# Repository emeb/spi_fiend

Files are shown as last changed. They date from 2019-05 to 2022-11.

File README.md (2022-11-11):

# spi_fiend
STM32F042-based USB to SPI device for programming iCE40 FPGAs

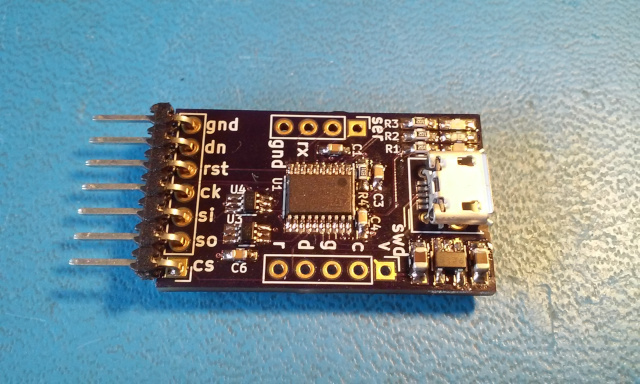
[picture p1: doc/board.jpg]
board


Most open-source projects that use Lattice iCE40 FPGAs rely on the FTDI
FT2232 High-speed UART/FIFO chip to provide a SPI interface for programming
the FPGA and SPI Flash chip which contains the bitstream for self-configuration
at power-up. I've got nothing against FTDI, but the chips are big, require
a crystal and are fairly expensive in DIY quantities. On top of that I've been
using STM32 for years and have been looking for an excuse to dig into some
more USB applications so a USB to SPI bridge seemed like a good place to start.

This device uses the small and inexpensive STM32F042F6P6 in a 20-pin TSSOP
package. It supports crystal-less USB operation by syncing its internal RC
oscillator to the USB SOF signal and has enough SRAM and Flash to support a
moderately complex feature set:

* USB powered
* Crystal-less operation
* Presents an ordinary ACM / CDC class device that looks like a serial port.
* Supports direct loading into the iCE40 SRAM for quick development cycles.
* Supports read/write/erase of standard SPI Flash devices used for FPGA configuration.
* Includes automatic swapping of MOSI/MISO when switching between FPGA and SPI Flash.
* MCU Serial port is pinned out for debugging and future expansion.

## prerequisites
To build this you will need the following tools:

* Kicad - schematic & PCB editor.
* GCC ARM Embedded - cross-compiler for ARM Cortex M: https://developer.arm.com/tools-and-software/open-source-software/developer-tools/gnu-toolchain/gnu-rm
* dfu-util - USB DFU driver application available in most distributions.
* Basic Linux user C compiler (for host application)

## Building Hardware

The board design is available in the 'hardware' directory. The Kicad PCB can
be submitted directly to OSHpark.com, or traditional Gerbers can be exported
using the application. Part values and packages are noted in the schematic.

Note: in the Revision 1 PCB layout the USB connector doesn't overhang the PCB
edge and there is a slight interference with the lower lip. Filing a slight
chamfer on the PCB edge under the connector will allow it to sit flush to the
board.

## Building Firmware

The [Firmware README](firmware/README.md) has instructions on building the
preferred firmware for the SPI Fiend.

## Building Host Application

The host appliction runs on a Linux PC and communicates with the hardware
device via standard USB Serial protocols. Build the host application by changing
to the 'host' directory and executing 'make'. The built-in help should provide
a guide to available options, but here's a quick list of common actions:

* load a binary into the FPGA: ./cdc_prog BINARY_FILE
* load a binary into SPI Flash: ./cdc_prog -a ADDRESS -w BINARY_FILE
* read SPI flash contents to a file: ./cdc_prog -a ADDRESS -l LENGTH -r > OUTPUT_FILE
* erase SPI FLASH block: ./cdc_prog -a ADDRESS -e
* read SPI Flash ID: ./cdc_prog -i

In ordinary operation, the LED nearest the USB connector lights to indicate powerup,
the center LED lights when an error is detected during operation and the outer LED
lights when programming SPI flash.

## Status
### 2019-05-06
Initial commit with hardware, firmware and host application

### 2022-11-11
Updated with dual firmware that supports FPGA, flash and UART

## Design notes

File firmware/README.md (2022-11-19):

# spi_fiend
This is the embedded firmware for the SPI Fiend. There are two different builds
here:
* single - this is the original firmware based on the ST USB stack. It provides
one CDC device which is able to program FPGAs or SPI flash chips.
* dual - this is the preferred new firmware based on the TinyUSB stack. It
provides two CDC devices, one for programming FPGA and SOI Flash and a second one
for serial UART I/O.

## Prerequisites
The preferred dual firmware requires the TinyUSB repo. Please be sure to get
that by executing the command
```
git submodule update --init
```

## Building
Go into the desired directory `dual` or `single` and run `make` to build the
binary file.

## Installing
Connect the SPI Fiend hardware to your host USB and press both the `BOOT` and
`RST` buttons to put it into DFU bootloader mode. Then run
```
make dfu
```
to load the new firmware binary into the hardware.

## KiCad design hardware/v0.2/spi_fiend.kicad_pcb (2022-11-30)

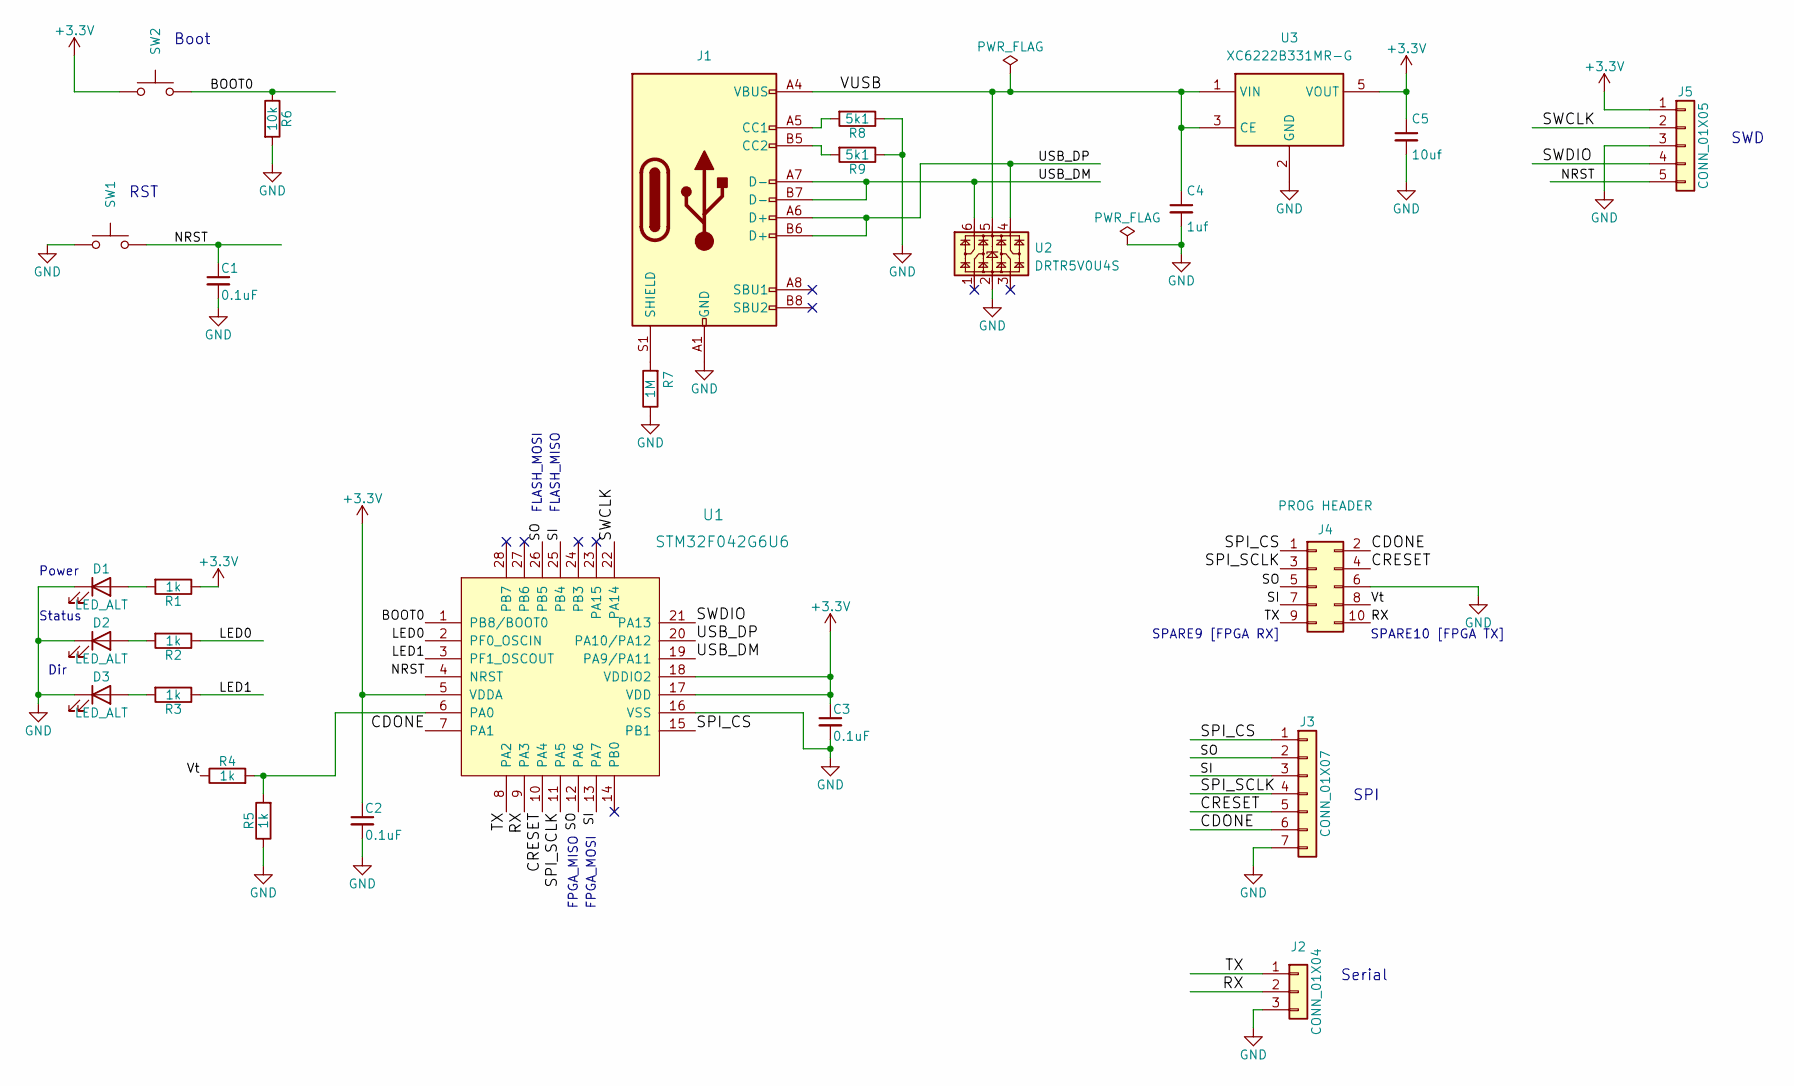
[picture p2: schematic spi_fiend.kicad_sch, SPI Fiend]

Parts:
C1, C2, C3: 0.1uF; C_0402_1005Metric
C4: 1uf; C_0402_1005Metric
C5: 10uf; C_0805_2012Metric
D1, D2, D3: LED_ALT; LED_0603_1608Metric
J1: USB_C_Receptacle_USB2.0; USB_C_Receptacle_HRO_TYPE-C-31-M-12
J2: CONN_01X04; PinHeader_1x03_P2.54mm_Vertical
J3: CONN_01X07; PinHeader_1x07_P2.54mm_Vertical
J4: PROG HEADER; PinHeader_2x05_P1.27mm_Vertical_SMD
J5: CONN_01X05; PinHeader_1x05_P2.54mm_Vertical
R1, R2, R3, R4, R5: 1k; R_0402_1005Metric
R6: 10k; R_0402_1005Metric
R7: 1M; R_0402_1005Metric
R8, R9: 5k1; R_0402_1005Metric
SW1, SW2: SW_Push; SW_SPST_PTS815
U1: STM32F042G6U6; IC_STM32F042G6U6
U2: DRTR5V0U4S; SOT-363_SC-70-6
U3: XC6222B331MR-G; SOT-23-5

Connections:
+3.3V: C2.1, C3.1, C5.1, J5.1, R1.1, SW2.1, U1.5 (VDDA), U1.17 (VDD), U1.18 (VDDIO2), U3.5 (VOUT)
/BOOT0: R6.1, SW2.2, U1.1 (PB8/BOOT0)
/CDONE: J3.6, J4.2, U1.7 (PA1)
/CRESET: J3.5, J4.4, U1.10 (PA4)
/LED0: R2.1, U1.2 (PF0_OSCIN)
/LED1: R3.1, U1.3 (PF1_OSCOUT)
/NRST: C1.1, J5.5, SW1.2, U1.4 (NRST)
/RX: J2.2, J4.10, U1.9 (PA3)
/SI: J3.3, J4.7, U1.13 (PA7), U1.25 (PB4)
/SO: J3.2, J4.5, U1.12 (PA6), U1.26 (PB5)
/SPI_CS: J3.1, J4.1, U1.15 (PB1)
/SPI_SCLK: J3.4, J4.3, U1.11 (PA5)
/SWCLK: J5.2, U1.22 (PA14)
/SWDIO: J5.4, U1.21 (PA13)
/TX: J2.1, J4.9, U1.8 (PA2)
/USB_DM: J1.A7 (D-), J1.B7 (D-), U1.19 (PA9/PA11), U2.6
/USB_DP: J1.A6 (D+), J1.B6 (D+), U1.20 (PA10/PA12), U2.4
/VUSB: C4.1, J1.A4 (VBUS), J1.A9 (VBUS), J1.B4 (VBUS), J1.B9 (VBUS), U2.5, U3.1 (VIN), U3.3 (CE)
/Vt: J4.8, R4.1
GND: C1.2, C2.2, C3.2, C4.2, C5.2, D1.1 (K), D2.1 (K), D3.1 (K), J1.A1 (GND), J1.A12 (GND), J1.B1 (GND), J1.B12 (GND), J2.3, J3.7, J4.6, J5.3, R5.1, R6.2, R7.1, R8.1, R9.1, SW1.1, U1.16 (VSS), U2.2, U3.2 (GND)
unnamed: D1.2 (A), R1.2
unnamed: D2.2 (A), R2.2
unnamed: D3.2 (A), R3.2
unnamed: J1.A5 (CC1), R8.2
unnamed: J1.B5 (CC2), R9.2
unnamed: J1.S1 (SHIELD), R7.2
unnamed: R4.2, R5.2, U1.6 (PA0)

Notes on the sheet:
FPGA_MISO
SWD
FPGA_MOSI
Serial
RST
Status
SPI
Power
Dir
FLASH_MOSI
Boot
SPARE9 [FPGA RX]
FLASH_MISO
SPARE10 [FPGA TX]

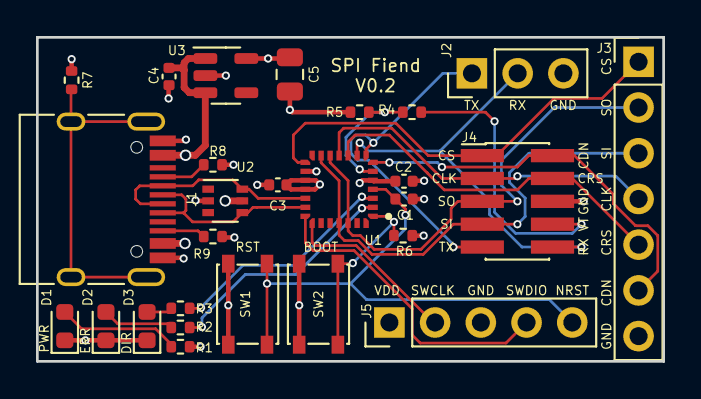
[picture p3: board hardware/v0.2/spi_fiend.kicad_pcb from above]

Board: 4 copper layers, 34.8 x 18.0 mm, 28 parts (1 on the bottom side), 27 nets.

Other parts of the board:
Ref**: Val**; avatar_small

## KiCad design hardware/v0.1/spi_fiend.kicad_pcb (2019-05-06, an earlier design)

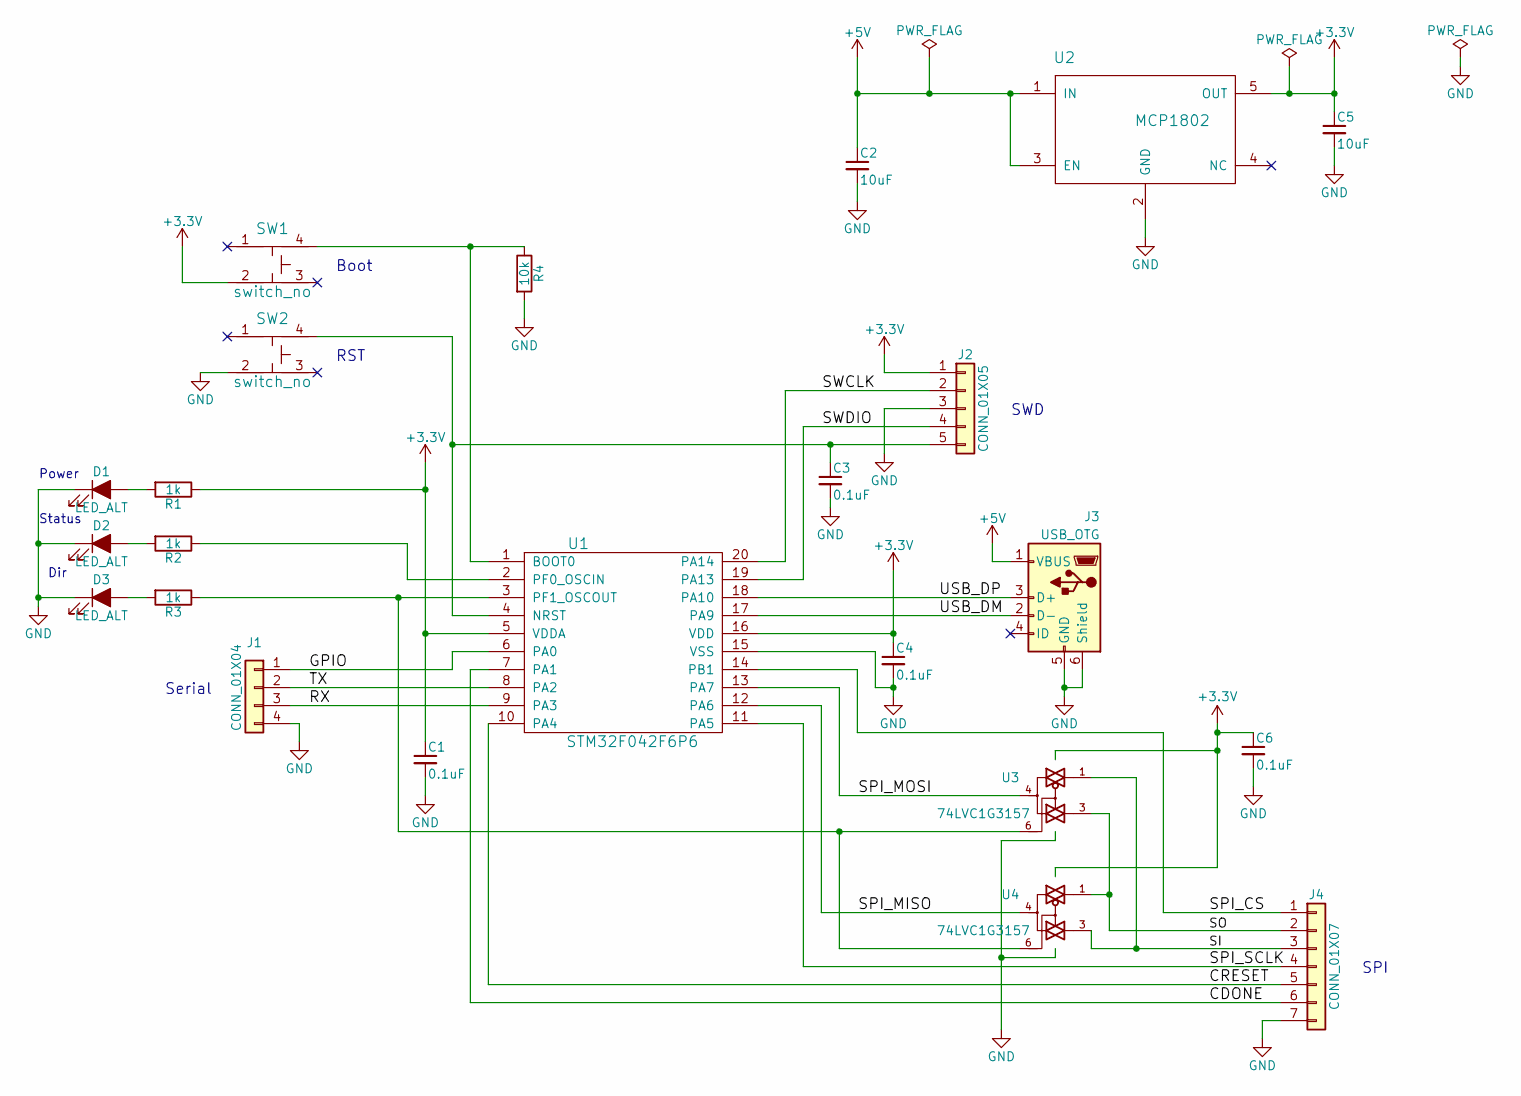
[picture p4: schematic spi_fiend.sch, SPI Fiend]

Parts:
C1, C3, C4, C6: 0.1uF; C_0603_HandSoldering
C2, C5: 10uF; C_0805_HandSoldering
D1, D2, D3: LED_ALT; LED_0603_HandSoldering
J1: CONN_01X04; Pin_Header_Straight_1x04_Pitch2.54mm
J2: CONN_01X05; Pin_Header_Straight_1x05_Pitch2.54mm
J3: USB_OTG; USB_Micro-B_10103594-0001LF_NoSlot
J4: CONN_01X07; Pin_Header_Straight_1x07_Pitch2.54mm
R1, R2, R3: 1k; R_0603_HandSoldering
R4: 10k; R_0603_HandSoldering
SW1, SW2: switch_no; PUSHBUTTON_SMD_KMR2
U1: STM32F042F6P6; TSSOP-20_4.4x6.5mm_Pitch0.65mm
U2: MCP1802; SOT-23-5_HandSoldering
U3, U4: 74LVC1G3157; SOT-363_SC-70-6_Handsoldering

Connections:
+3V3: C1.1, C4.1, C5.1, C6.1, J2.1, R1.1, SW1.2, U1.5 (VDDA), U1.16 (VDD), U2.5 (OUT), U3.5 (VCC), U4.5 (VCC)
+5V: C2.1, J3.1 (VBUS), U2.1 (IN), U2.3 (EN)
/CDONE: J4.6, U1.7 (PA1)
/CRESET: J4.5, U1.10 (PA4)
/GPIO: J1.1, U1.6 (PA0)
/RX: J1.3, U1.9 (PA3)
/SI: J4.3, U3.1, U4.3
/SO: J4.2, U3.3, U4.1
/SPI_CS: J4.1, U1.14 (PB1)
/SPI_MISO: U1.12 (PA6), U4.4
/SPI_MOSI: U1.13 (PA7), U3.4
/SPI_SCLK: J4.4, U1.11 (PA5)
/SWCLK: J2.2, U1.20 (PA14)
/SWDIO: J2.4, U1.19 (PA13)
/TX: J1.2, U1.8 (PA2)
/USB_DM: J3.2 (D-), U1.17 (PA9)
/USB_DP: J3.3 (D+), U1.18 (PA10)
GND: C1.2, C2.2, C3.2, C4.2, C5.2, C6.2, D1.1 (K), D2.1 (K), D3.1 (K), J1.4, J2.3, J3.5 (GND), J3.6 (Shield), J4.7, R4.2, SW2.2, U1.15 (VSS), U2.2 (GND), U3.2 (GND), U4.2 (GND)
unnamed: C3.1, J2.5, SW2.4, U1.4 (NRST)
unnamed: D1.2 (A), R1.2
unnamed: D2.2 (A), R2.2
unnamed: D3.2 (A), R3.2
unnamed: R2.1, U1.2 (PF0_OSCIN)
unnamed: R3.1, U1.3 (PF1_OSCOUT), U3.6, U4.6
unnamed: R4.1, SW1.4, U1.1 (BOOT0)

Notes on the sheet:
Boot
RST
Serial
SPI
SWD
Power
Status
Dir

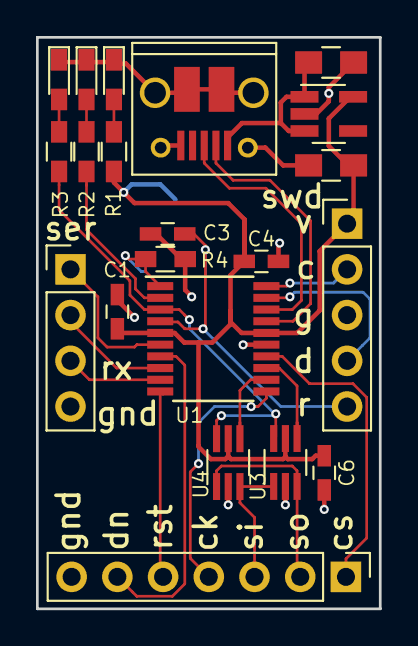
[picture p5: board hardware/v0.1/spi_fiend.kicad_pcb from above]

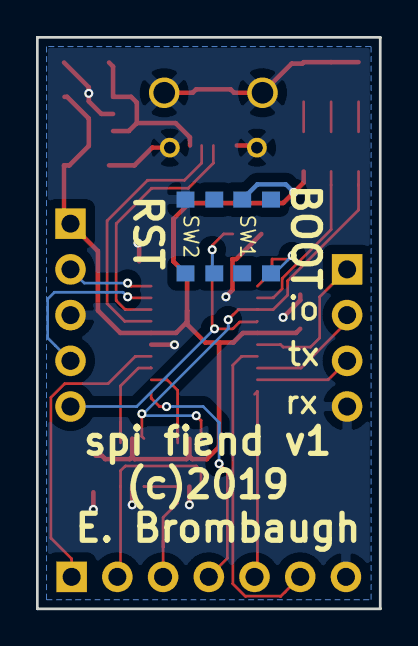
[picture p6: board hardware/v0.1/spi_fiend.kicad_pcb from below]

Board: 2 copper layers, 19.1 x 31.8 mm, 23 parts (2 on the bottom side), 25 nets.

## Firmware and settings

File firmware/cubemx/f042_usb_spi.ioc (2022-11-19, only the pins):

Mcu.UserName=STM32F042F6Px
PA0.GPIO_Label=GPIO0
PA0.Signal=GPIO_Output
PA1.GPIO_Label=CDONE
PA1.Signal=GPIO_Input
PA11.Signal=USB_DM
PA12.Signal=USB_DP
PA13.Signal=SYS_SWDIO
PA14.Signal=SYS_SWCLK
PA2.Signal=USART2_TX
PA3.Signal=USART2_RX
PA4.GPIO_Label=CRST
PA4.Signal=GPIO_Output
PA5.Signal=SPI1_SCK
PA6.Signal=SPI1_MISO
PA7.Signal=SPI1_MOSI
PB1.GPIO_Label=SPI_CS
PB1.Signal=GPIO_Output
PB8.GPIO_Label=BOOT
PB8.Signal=GPIO_Output
PF0-OSC_IN.GPIO_Label=Status
PF0-OSC_IN.Signal=GPIO_Output
PF1-OSC_OUT.GPIO_Label=DIR
PF1-OSC_OUT.Signal=GPIO_Output

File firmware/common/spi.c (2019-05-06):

/*
 * spi.h - spi driver for F042_usb_spi
 * 01-23-2019 E. Brombaugh
 */

#include "spi.h"
#include "tim.h"
#include "led.h"

/* macros to define pins */
#define SPI_CS_PIN                        GPIO_PIN_1
#define SPI_CS_GPIO_PORT                  GPIOB
#define SPI_RST_PIN                       GPIO_PIN_4
#define SPI_RST_GPIO_PORT                 GPIOA
#define SPI_DONE_PIN                      GPIO_PIN_1
#define SPI_DONE_GPIO_PORT                GPIOA

/* macros for GPIO setting */
#define SPI_CS_LOW()     HAL_GPIO_WritePin(SPI_CS_GPIO_PORT,SPI_CS_PIN,GPIO_PIN_RESET)
#define SPI_CS_HIGH()    HAL_GPIO_WritePin(SPI_CS_GPIO_PORT,SPI_CS_PIN,GPIO_PIN_SET)
#define SPI_RST_LOW()    HAL_GPIO_WritePin(SPI_RST_GPIO_PORT,SPI_RST_PIN,GPIO_PIN_RESET)
#define SPI_RST_HIGH()   HAL_GPIO_WritePin(SPI_RST_GPIO_PORT,SPI_RST_PIN,GPIO_PIN_SET)
#define SPI_DONE_GET()   HAL_GPIO_ReadPin(SPI_DONE_GPIO_PORT, SPI_DONE_PIN)
#define ICE5_SPI_DUMMY_BYTE   0xFF
#define SPI_SWAP_MOSI()  led_on(LED1)
#define SPI_NORM_MOSI()  led_off(LED1)


/* SPI port handle */
static SPI_HandleTypeDef SpiHandle;

/* flash write state */
uint32_t fpw_addr, fpw_len, fpw_ptr;
uint8_t fpw_buffer[256];

/*
 * get SPI signals on/off the bus
 */
void spi_oe(uint8_t state)
{
	GPIO_InitTypeDef GPIO_InitStructure;
	
	if(state)
	{
		/* Configure SPI1 CLK/MOSI/MISO as alternate function push-pull */
		GPIO_InitStructure.Pin = GPIO_PIN_7|GPIO_PIN_6|GPIO_PIN_5;
		GPIO_InitStructure.Mode = GPIO_MODE_AF_PP;
		GPIO_InitStructure.Speed = GPIO_SPEED_FREQ_HIGH;
		GPIO_InitStructure.Pull = GPIO_NOPULL;
		GPIO_InitStructure.Alternate = GPIO_AF0_SPI1;
		HAL_GPIO_Init(GPIOA, &GPIO_InitStructure);
	}
	else
	{
		/* Configure SPI1 CLK/MOSI/MISO as input /w pullup */
		GPIO_InitStructure.Pin = GPIO_PIN_7|GPIO_PIN_6|GPIO_PIN_5;
		GPIO_InitStructure.Mode = GPIO_MODE_INPUT;
		GPIO_InitStructure.Speed = GPIO_SPEED_FREQ_HIGH;
		GPIO_InitStructure.Pull = GPIO_PULLUP;
		GPIO_InitStructure.Alternate = GPIO_AF0_SPI1;
		HAL_GPIO_Init(GPIOA, &GPIO_InitStructure);
	}
}

/*
 * Initialize the spi port and associated controls
 */
void spi_init(void)
{
	GPIO_InitTypeDef GPIO_InitStructure;
	
	/* Enable GPIO clocks */
	__HAL_RCC_GPIOA_CLK_ENABLE();
	__HAL_RCC_GPIOB_CLK_ENABLE();

	/* Setup GPIO control bits */
	SPI_RST_HIGH();
	SPI_CS_HIGH();
	
	/* CS pin configuration - OD w/ PU to allow multi master */
	GPIO_InitStructure.Pin =  SPI_CS_PIN;
	GPIO_InitStructure.Mode = GPIO_MODE_OUTPUT_OD;
	GPIO_InitStructure.Speed = GPIO_SPEED_FREQ_HIGH;
	GPIO_InitStructure.Pull = GPIO_PULLUP;
	HAL_GPIO_Init(SPI_CS_GPIO_PORT, &GPIO_InitStructure);
    
	/* RST pin configuration */
	GPIO_InitStructure.Pin =  SPI_RST_PIN;
	GPIO_InitStructure.Mode = GPIO_MODE_OUTPUT_PP;
	GPIO_InitStructure.Speed = GPIO_SPEED_FREQ_HIGH;
	GPIO_InitStructure.Pull = GPIO_NOPULL;
	HAL_GPIO_Init(SPI_RST_GPIO_PORT, &GPIO_InitStructure);
    
	/* Disable SPI outputs */
	spi_oe(0);
	
	/* Enable the SPI peripheral */
    __HAL_RCC_SPI1_CLK_ENABLE();
    
	SpiHandle.Instance               = SPI1;
	SpiHandle.Init.BaudRatePrescaler = SPI_BAUDRATEPRESCALER_8;
	SpiHandle.Init.Direction         = SPI_DIRECTION_2LINES;
	SpiHandle.Init.CLKPhase          = SPI_PHASE_1EDGE;
	SpiHandle.Init.CLKPolarity       = SPI_POLARITY_LOW;
	SpiHandle.Init.DataSize          = SPI_DATASIZE_8BIT;
	SpiHandle.Init.FirstBit          = SPI_FIRSTBIT_MSB;
	SpiHandle.Init.TIMode            = SPI_TIMODE_DISABLE;
	SpiHandle.Init.CRCCalculation    = SPI_CRCCALCULATION_DISABLE;
	SpiHandle.Init.CRCPolynomial     = 7;
	SpiHandle.Init.NSS               = SPI_NSS_SOFT;
	SpiHandle.Init.Mode              = SPI_MODE_MASTER;
	HAL_SPI_Init(&SpiHandle);

	/* Enable the SPI peripheral */
    __HAL_SPI_ENABLE(&SpiHandle);
}

/*
 * send a byte and receive a byte via spi
 */
uint8_t spi_txrx(uint8_t data)
{
	/* Wait until the transmit buffer is empty */
	while(__HAL_SPI_GET_FLAG(&SpiHandle, SPI_FLAG_TXE) == RESET)
	{
	}

	/* Send the byte */
	*(__IO uint8_t *) ((uint32_t)SPI1+0x0C) = data;
	
	/* Wait to receive a byte*/
	while(__HAL_SPI_GET_FLAG(&SpiHandle, SPI_FLAG_RXNE) == RESET)
	{
	}

	/* get the byte read from the SPI bus */ 
	data = *(__IO uint8_t *) ((uint32_t)SPI1+0x0C);
	
	return data;
}

/*
 * Send a block of data bytes via SPI
 */
uint32_t spi_send_data(uint8_t *data, uint32_t sz)
{	
    /* send all bytes */
	while(sz--)
    {
        spi_txrx(*data++);
	}
    
    return 0;
}

/*
 * start the config process
 */
uint8_t spi_config_start(void)
{
    uint8_t retval = 0;
	uint32_t timeout;
	
	/* Enable SPI port onto bus */
	spi_oe(1);
	
	/* drop reset bit */
	SPI_RST_LOW();
	
	/* wait 1us */
	tim_usleep(1);
    
	/* drop CS bit to signal slave mode */
	SPI_CS_LOW();
	
	/* delay >200ns to allow FPGA to recognize reset */
	tim_usleep(200);
    
	/* Wait for done bit to go inactive */
	timeout = 1000;
	while(timeout && (SPI_DONE_GET()==GPIO_PIN_SET))
	{
		timeout--;
	}
	if(!timeout)
	{
		/* Done bit didn't respond to Reset */
		retval = 1;
	}
    
	/* raise reset w/ CS low for SPI SS mode */
	SPI_RST_HIGH();
	
	/* delay >300us to allow FPGA to clear */
	tim_usleep(2000);
    
    return retval;
}

/*
 * finish the config process
 */
uint8_t spi_config_finish(void)
{
    uint8_t retval = 0;
	uint32_t timeout;
	
    /* diagnostic - raise CS for final runout */
	//SPI_CS_HIGH();
    
    /* send clocks while waiting for DONE to assert */
	timeout = 1000;
	while(timeout && (SPI_DONE_GET()==GPIO_PIN_RESET))
	{
		spi_txrx(ICE5_SPI_DUMMY_BYTE);
		timeout--;
	}
	if(!timeout)
	{
		/* FPGA didn't configure correctly */
		retval = 1;
	}
	
	/* send at least 49 more clocks */
	spi_txrx(ICE5_SPI_DUMMY_BYTE);
	spi_txrx(ICE5_SPI_DUMMY_BYTE);
	spi_txrx(ICE5_SPI_DUMMY_BYTE);
	spi_txrx(ICE5_SPI_DUMMY_BYTE);
	spi_txrx(ICE5_SPI_DUMMY_BYTE);
	spi_txrx(ICE5_SPI_DUMMY_BYTE);
	spi_txrx(ICE5_SPI_DUMMY_BYTE);

	/* Raise CS bit for subsequent slave transactions */
	SPI_CS_HIGH();
	
	/* Remove SPI port from bus */
	spi_oe(0);
	
	/* no error handling for now */
	return retval;
}

/*
 * prep for flash access
 */
void spi_flash_access(uint8_t state)
{
	if(state)
	{
		/* set up */
		SPI_RST_LOW();		/* disable the FPGA to get the bus */
		SPI_SWAP_MOSI();	/* swap mosi/miso for flash access */
		spi_oe(1);			/* Enable SPI port onto bus */
	}
	else
	{
		/* teardown */
		spi_oe(0);			/* Remove SPI port from bus */
		SPI_NORM_MOSI();	/* restore mosi/miso order */
		SPI_RST_HIGH();		/* enable the FPGA */
	}
}

/*
 * powerup flash
 */
void spi_flash_powerup(void)
{
	SPI_CS_LOW();			/* drop CS bit to access the memory */
	
	/* power up command */
	spi_txrx(0xab);
	
	SPI_CS_HIGH();			/* Raise CS to disable the memory */
	
}

/*
 * flash write enable
 */
void spi_flash_wen(void)
{
	SPI_CS_LOW();			/* drop CS bit to access the memory */
	
	/* write enable command */
	spi_txrx(0x06);
	
	SPI_CS_HIGH();			/* Raise CS to disable the memory */
	
}
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

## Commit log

2019-05-06 Add hardware, firmware, host and documentation
    [spi_fiend.kicad_pcb, spi_fiend.sch]
2022-11-17 move spi driver to common
2022-11-26 Updated with official PID code from pid.codes
2022-11-27 Started V0.2 hardware
    [spi_fiend.kicad_pcb, spi_fiend.kicad_sch, spi_fiend.sch]
2022-11-27 Start layout
    [spi_fiend.kicad_pcb]
2022-11-27 P&R almost done.
    [spi_fiend.kicad_pcb, spi_fiend.kicad_sch]
2022-11-27 Revert "P&R almost done."
    This reverts commit 97a49ac74aeb3e6297260b20c9d5898586bb1314.
    [spi_fiend.kicad_pcb, spi_fiend.kicad_sch]
2022-11-30 Fix 3D stuff
    [spi_fiend.kicad_pcb]

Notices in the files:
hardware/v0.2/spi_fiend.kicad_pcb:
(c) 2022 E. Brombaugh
